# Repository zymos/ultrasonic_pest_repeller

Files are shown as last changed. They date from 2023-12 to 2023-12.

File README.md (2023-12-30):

# Ultrasonic (super annoying) Pest Repeller
Beeps dual ultrasonic frequencies with random durration and pauses. Also flashes LEDs.  It activates when motion is detected and at random times.

## MCU
I had a bunch of ATtiny26L, so I used them.  The code is so simple, you can easily convert it to any MCU.
- Vcc = 5V
- internal oscilator, 1MHz
- Fuses OK (E:FF, H:F7, L:E1)
-
## Oscilator
I used an NE556(dual 555) as two astable multivibrator. They drove two ultrasonic piezo speakers, at two different frequencies. Rodents can hear up to 80kHz (In their youth). Humans hear up to 20kHz. I chose 30kHz and 40kHz for the ultrasonic frequencies.
- Vcc = 12V
- freq-1 = 38kHz
- freq-2 = 55kHz
- Reset pin is controlled by the MCU 
- Output to drive ultrasonic speakers

## PIR
I used two cheap PIR, HC-SR501
- Vcc = 5V
- V-pir-output-high = 3.3-3.5V
- V-pir-output-low = 0.4-0.8V
- Outputs to OR-gate then to inturrupt on MCU
 - V-pir-out high/low too close to V-mcu-in high/low for diode OR-gate so I used a pin change interupt

## Ultrasonic speakers
- two cheap piezo ultrasonic speakers
- Driven = 12V square wave
- freq-1 = 38kHz
- freq-2 = 55kHz

## Power
- Vpower-in = 12V
- Vcc-osc(555) = 12V
- Vcc-pir and Vcc-mcu = 5V via a 7805
- V-led = 3.3V via cheap DC-DC converter

## References
- Hearing ranges:  https://en.wikipedia.org/wiki/Hearing_range#/media/File:Animal_hearing_frequency_range.svg

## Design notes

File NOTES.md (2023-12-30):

555 timer
- if you dont put a cap on control pin, you will get lower frequency harmonics and frequency will oscilate by around 1-2%

MCU
- Vih-min for pins 7,8 are 0.8Vcc, 
 - all others are 0.6Vcc
 - So at 5V pins 7,8 wont work with 3.3V I/O

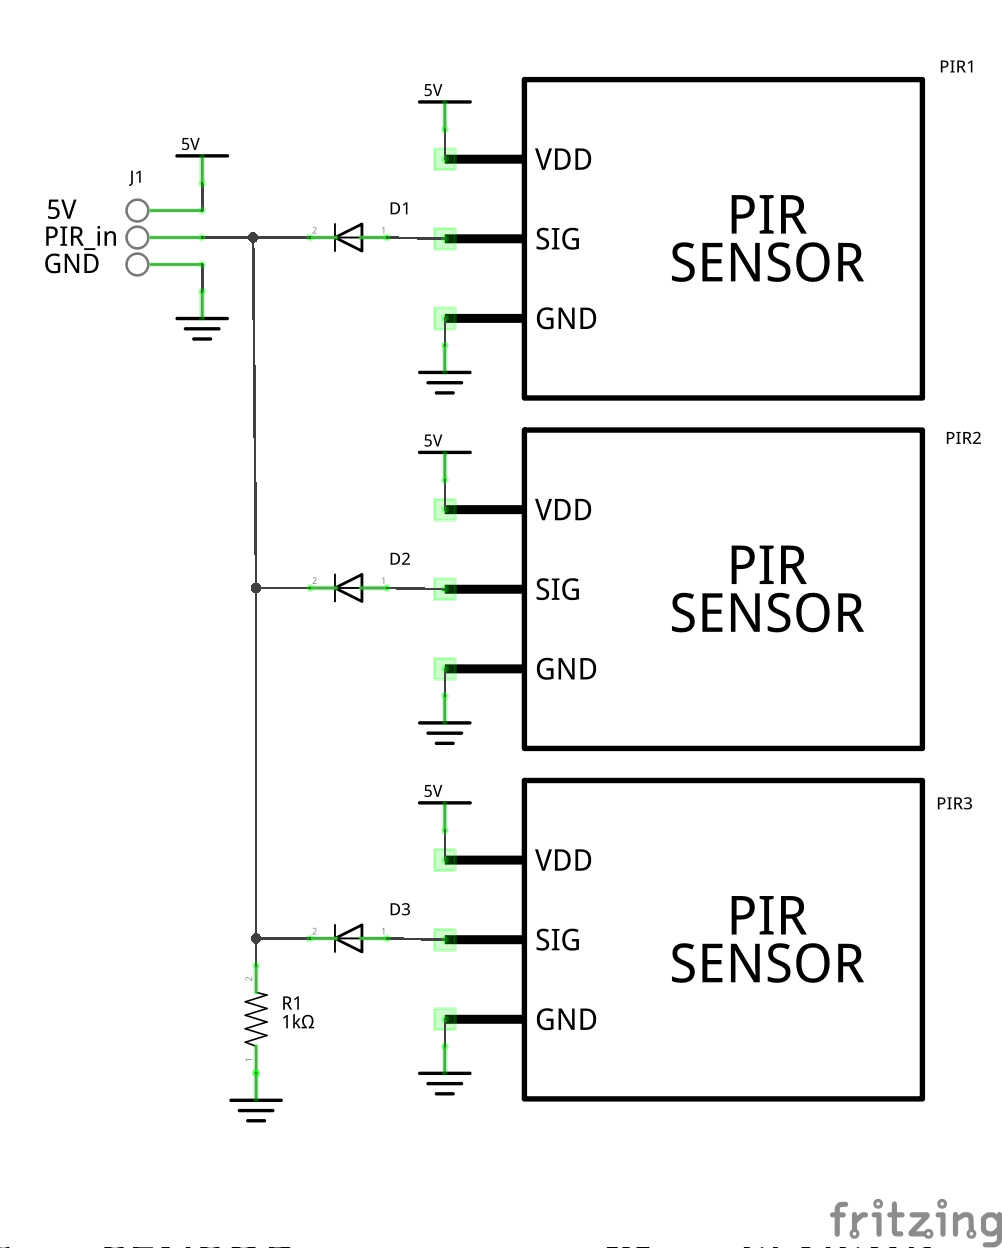
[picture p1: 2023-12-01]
schematics/PIR_schem.png

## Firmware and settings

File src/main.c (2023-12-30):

/*
 * Animal Deturent Ultrasonic Beeper and Flasher
 *
 *    Description: really annoy (hopfully) for pests,
 *       random ultrasonic beeps, 2-tone, and flashes
 *       Code is for Attiny26, but should be easly modified to any AVR
 *    
 *    Credits: Zef the Tinker, 2023/11
 *
 */ 

// define the frequency
#define	F_CPU	1000000
#define 	XTAL   1000000
#define __AVR_ATtiny26__ 1 // to use other MCU you need to change this

// #include <stdlib.h>
#include <avr/io.h>
#include <util/delay.h>
#include <avr/interrupt.h>



/////////////////////////////////////////////////////////////////////////////
// Config
//

#define TIMED_BEEP_INTERVAL 10 // Timed auto-activate interval (minutes)

// Deterrent action is (20 beeps * NUM_OF_LOOPS) + (4 * LED_BLINK_CNT)
#define NUM_OF_LOOPS 5 // number of times to loop through beeps (20 beeps * NUM_OF_LOOPS)
#define LED_BLINK_CNT 5 // number of times led will blink

// DEBUGING:  Normal opperation is 0/0/0 
#define DISABLE_IRQ 0 // disable interrupt for testing
#define ALL_ON 0 // LED and SPEAKER always on, no blinks
#define CONSTANT_BEEPING 0 // ALWAYS beeps and flashes, no motion sense


/////////////////////////////////////////////////////////////////////////////
// PINS
//
//    if you use other MCU you need to change this
//
// Interrupts
//    - PC interrupt1: PB[7:4], PA[7:6], PA[3]
//    - PC interrupt0: PB[3:0]
//    - interrupt0: PB[6]
//
// Pinout
// 1 PB0 (MOSI/DI/SDA/OC1A/PCINT0/PROGRAMMER) [PROGRAMER]
// 2 PB1 (MISO/DO/OC1A/PCINT0/PROGRAMMER)     [PROGRAMER]
// 3 PB2 (SCK/SCL/OC1B/PCINT0/PROGRAMMER)     [PROGRAMER]
// 4 PB3 (OC1B/PCINT0)                        [X]
// 5 VCC
// 6 GND
// 7 PB4 (ADC7/XTAL1/PCINT1)             [X]
// 8 PB5 (ADC8/XTAL2/PCINT1)             [X]
// 9 PB6 (ADC9/INT0/T0/PCINT1)           [PIR1]
// 10 PB7 (ADC10/RESET/PCINT1/PROGRAMER) [PROGRAMER]

// 20 PA0 (ADC0)                        [MODE SWITCH] 
// 19 PA1 (ADC1)                        [X]
// 18 PA2 (ADC2)                        [X]  
// 17 PA3 (AREF/PCINT1)                 [PIR0 SENSOR]  
// 16 GND
// 15 AVCC
// 14 PA4 (ADC3)                        [MCU ACTIVE LED]
// 13 PA5 (ADC4)                        [LED FLASH]
// 12 PA6 (ADC5/AIN0/PCINT1)            [SPEAKER0]
// 11 PA7 (ADC6/AIN1/PCINT1)            [SPEAKER1]
//
// notes: Vih-min for pins 7,8 are 0.8Vcc, 
//   all others are 0.6Vcc
//   So at 5V pins 7,8 need to be >4.0V
//
#define PIN_SPEAK0 PA6 // ultra-sonic speaker0, output
#define PIN_SPEAK1 PA7 // ultra-sonic speaker1, output

#define PIN_LED0 PB4 //PA5 // flashing LED, output
#define PIN_LED_PWR_ON PA4 // LED to indicate MCU is up and running, output

#define PIN_MODE_SW PA0 // Mode switch

#define PIN_PIRA PA3 // PIR
#define PIN_PIRB PB6 // PIR






//////////////////////////////////////////////////////////////////////////////
// Global vars
//

long time_counter = 0; // for timed auto activate interval

#define MINUTE_FUDGE_FACTOR 1357000 //60 * 226000 ish

#define sleep_delay_multi 500 // multiplier for delay between auto-activate

#define LOOP_DELAY 100 // microseconds

#define delay_multi 50 // multiplier for the 1ms delay

// RANDOM beep durrations (psuedo-random)
const int beep_length[20] = {11,72,38,42,65,22,47,88,22,56
                              ,9,55,12,77,41,99,88,10,30,50 }; // list of random duration


//////////////////////////////////////////////////////////////////////////////
// Code
//


// make sure the freq isnt redefine, not sure if needed
#ifdef F_CPU
   #undef F_CPU
#endif
#define F_CPU	1000000

#ifdef XTAL
   #undef XTAL
#endif
#define XTAL   1000000



//////////////////////////////
// Animal Deturent function
//    beeps and flashes, 
//    psuedo random durration and pauses
//    
void animal_det(void){
   int pointer1 = 2; // used for speaker1 as random num list offset

   // repeat loops of array
   for(int q=0; q<NUM_OF_LOOPS; q++){
      // loop the psuedo-radom array
      //  this beep for each number in array
      for(int x=0; x < sizeof(beep_length)/sizeof(beep_length[0]); x++){ //loop the array
     
         // Speakers
         PORTA &= ~(1 << PIN_SPEAK0); //speaker 0 off
         PORTA &= ~(1 << PIN_SPEAK1); //speaker 1 off
         for(int n=0; n<100; n++){ //on/off period
            if(pointer1 == 10){ // for ponter1 offset
               pointer1 = 0;
            }
            if(n > beep_length[x]){
               PORTA |= (1 << PIN_SPEAK0); //speaker 0 on
            }
            if(n > beep_length[pointer1]){
               PORTA |= (1 << PIN_SPEAK1); //speaker 1 on
            }
            _delay_ms(3 * delay_multi/10); 
         }   

         //LED
         if(x % 2 == 0){ // activate LED every N beeps
            for(int p=0; p<LED_BLINK_CNT; p++){
               PORTB |= (1 << PIN_LED0); //led on
               _delay_ms(1 * delay_multi); 
               PORTB &= ~(1 << PIN_LED0); //led off
               _delay_ms(1 * delay_multi);
            }
         }

         // inc pointer for speaker1
         pointer1++;
      }
      
      // turn everything off
      PORTB &= ~(1 << PIN_LED0); //led 0 off
      PORTA &= ~(1 << PIN_SPEAK0); //speaker 0 off
      PORTA &= ~(1 << PIN_SPEAK1); //speaker 1 off

      _delay_ms(3 * delay_multi);
   }
}

////////////////////////////
// Interrupt on INT0
//  to use other MCU you need to change this
//    INT0_vect: interrupt 0
//    IO_PINS_vect: pin change interrupt (all?)

ISR(IO_PINS_vect){ // to use other MCU you need to change this
   //   See: https://www.gnu.org/savannah-checkouts/non-gnu/avr-libc/user-manual/group__avr__interrupts.html
   
   // if interrupt and one of PIRs active
   if( (PINB & (1 << PIN_PIRB) || PINA & (1 << PIN_PIRA) ) && !DISABLE_IRQ && !ALL_ON){

      // (PINA & (1 << PIN_MODE_SW)){{

         // activate deturrent
         animal_det();
      //}}

   }
}




/////////////////
// Initalize
void initialize(void){
   // set PORTA to all outputs, except PA3
   // PORTB is already inputs
   // to use other MCU you need to change this
   DDRA = 0b11110110; // set PORTA to all outputs, except PA3, PA0 // to use other MCU you need to change this

   // Set LED as output
   DDRB |= (1<<PIN_LED0);

	
   // ATtiny26
   //    MCUCR: MCU Control Register
   //       ISC01=1 ISC00=1 The rising edge of INT0 generates an interrupt request.
   //    GIMSK: General Interrupt Mask Register
   //       INT0: interrupt0
   //       PCIE1: pin change interrupt 1  PB[7:4], PA[7:6] and PA[3]
   //       PCIE0:  pin change interrupt 0 PB[3:0]
   //    GIFR: General Interrupt Flag Register
   //       GIFR(PCIF) flag when PC interrupt
   //    INTF0: 6
 // Using PB4 and PB5 for PCINT1
   MCUCR |= (1<<ISC00); //rising edge // to use other MCU you need to change this
   MCUCR |= (1<<ISC01); //rising edge // to use other MCU you need to change this
   // GIMSK |= (1<<INT0); // enable INT0 // to use other MCU you need to change this
   GIMSK |= (1<<PCIE1); // enable PCINT1 // to use other MCU you need to change this

   // timer0
   // CS02=1, CS01=0, CS00=1: CLK/1024
   // TCCR0


   sei();     // Enable global interrupts by setting global interrupt enable bit in SREG


   // turn on LED indicator to show MCU active
   PORTA |= (1<<PIN_LED_PWR_ON); // to use other MCU you need to change this

}


///////////
// Main
int main(void)
{
   initialize();

	while(1) {
      if(ALL_ON){ // Mode: all lights and sound on (debug forced)
         PORTB |= (1 << PIN_LED0);
         PORTA |= (1 << PIN_SPEAK0);
         PORTA |= (1 << PIN_SPEAK1); 
      }else if(CONSTANT_BEEPING){ // Mode: Constant beeping mode (debug forced)
         animal_det();
      // }else if(PINA & (1 << PIN_MODE_SW)){ // Mode: (switch set)
      //    animal_det();
      // }
      }else if( time_counter > TIMED_BEEP_INTERVAL * 60000 ){//TIMED_BEEP_INTERVAL * MINUTE_FUDGE_FACTOR / LOOP_DELAY){ // timed beeping
         animal_det();
         time_counter = 0; // reset counter
      }
      _delay_ms(1); //LOOP_DELAY);
      time_counter++;

   } // infinite loop


} //main
